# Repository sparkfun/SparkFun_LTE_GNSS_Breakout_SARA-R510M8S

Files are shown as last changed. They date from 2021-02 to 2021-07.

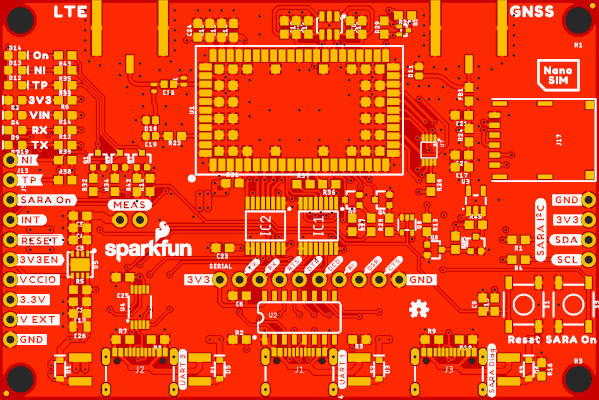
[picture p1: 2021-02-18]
img/Top.png

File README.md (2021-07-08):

# SparkFun LTE GNSS Breakout - SARA-R510M8S

LTE GNSS Breakout - SARA-R5 (GPS-18031 (https://www.sparkfun.com/products/18031)

The u-blox SARA-R510M8S module is a secure cloud LTE Cat M1, LTE Cat NB2 solution based on u-blox's UBX-R5 cellular chipset.
The SARA-R510M8S has an integrated u-blox M8 GNSS receiver chip and a separate GNSS antenna interface.

The SARA-R5's UART interface can be configured into one of five variants, providing connectivity over one or two UARTs. A separate USB port
provides access to the SARA's trace log for diagnostic purposes. This breakout provides access to all three interfaces (UART1, UART2 and SARA Diag)
via three separate USB-C connections. All eight 3.3V serial signals are available on a 0.1"-pitch breakout header.

## Repository Contents

- **/Documentation** - Datasheets etc.
- **/Hardware** - Eagle PCB, SCH and LBR design files. Full schematic in PDF format.
- **[LICENSE.md](./LICENSE.md)** - License details

## Documentation

- **[SparkFun u-blox SARA-R5 Arduino Library](https://github.com/sparkfun/SparkFun_u-blox_SARA-R5_Arduino_Library)** - Arduino library for the SARA-R5 module.
- **[Hookup Guide](https://learn.sparkfun.com/tutorials/lte-gnss-breakout---sara-r5-hookup-guide)** - Hookup Guide for the LTE GNSS Breakout - SARA-R5.

## UART 1 & 2

The board comes pre-configured to support interface variants 0 and 1 (single UART, 8-wire connectivity). If you want to use variants 2-4 (dual UART),
you will need to:
- Open the split pads adjacent to the **DTR**, **DCD**, **RI** and **DSR** breakout pins
- Close the solder split pads labelled **TXD2**, **RXD2**, **RTS2** and **CTS2**
- Open the **OUT** split pad labelled **DSR O RTS2 I** and close the adjacent **IN** solder split pad

The serial signals on the breakout pins are all 3.3V. Level-shifting circuits connect them to the SARA's 1.8V UART pins.

## Power Options

The board can draw 5V power from any or all of the USB-C connectors. Optionally, you can provide power via the **V EXT** breakout pin: 3.7V Min; 6.0V Max.

If you want to use **V EXT** as an output, you can bypass the DVEXT protection diode by closing the **V EXT Diode** solder split pad.

The board's 3.3V current draw can be monitored via the **MEAS** header pins. Open the split pad linking these pins if required.

## Additional Breakout Pins

- **NI** - Network Indicator will be _low_ when the SARA is on and the network is available.
- **TP** - GNSS Timing Pulse (PPS) pin will pulse low/high when configured by the **+UTIME=1,1** command. Please see the [AT Commands Manual](./Documents/SARA-R5_ATCommands_(UBX-19047455).pdf) for more details.
- **SARA On** - pull low for 5 seconds then release to turn the SARA off. Pull low briefly again to turn the SARA back on. You can tell if the SARA is powered by monitoring the **VCCIO** 1.8V pin.
- **INT** - by default this pin is connected to the SARA's bi-directional **EXT INT** pin. It can optionally be connected to **GPIO3** by reconfiguring the **SARA INT** split pad.
- **~RESET** - pull low and release to reset the SARA.
- **SARA I<sup>2</sup>C** - provides access to the SARA's I<sup>2</sup>C SDA and SCL pins.
- **3V3EN** - pull this pin low to disable the 3.3V supply completely. _Note: you may want to turn the SARA off using the **SARA On** pin first, so it disconnects from the network correctly._

**NI**, **TP**, **SARA On**, **INT**, **~RESET**, **SDA** and **SCL** are all 3.3V. Level-shifting circuits connect them to the SARA's 1.8V I/O pins.

_**Important Note**: **VCCIO** is 1.8V. You may need to connect it to an analog input to sense the voltage correctly._

_**Important Note**: **3V3EN** is pulled-up to VIN (5V) via a 100K resistor. We recommend using a switch or open-collector / open-drain output to pull **3V3EN** low._

## Switches

- **Reset** - pressing this switch will reset the SARA.
- **SARA On** - pressing and holding this switch for five seconds will turn the SARA off. Press briefly to turn the SARA back on again.

## GNSS Antenna Power

The board provides 3.3V power for an active GNSS antenna. By default the antenna power is enabled whenever the SARA is on. You can reconfigure the **ANT GNSS PWR**
split pad to optionally control the antenna power via the SARA's GPIO2 pin.

The GPIO2 pin can be controlled using the **+UGPIOC=23,0,1** command.
Please see the [AT Commands Manual](./Documents/SARA-R5_ATCommands_(UBX-19047455).pdf) for more details.

## Product Versions

- [GPS-18031](https://www.sparkfun.com/products/18031) - Initial Release

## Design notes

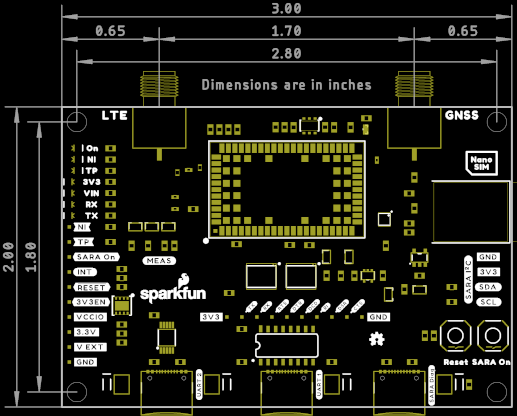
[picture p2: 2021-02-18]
img/Dimensions.png

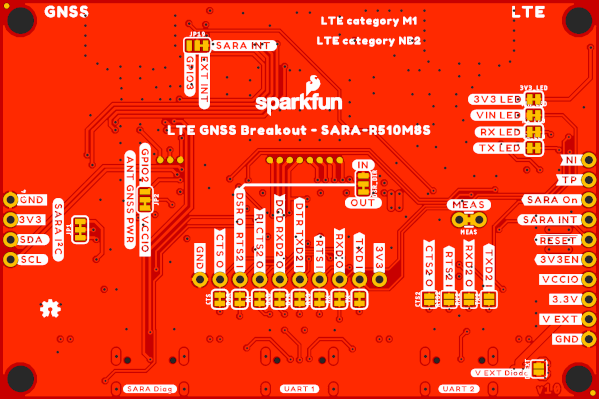
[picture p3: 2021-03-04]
img/Bottom.png

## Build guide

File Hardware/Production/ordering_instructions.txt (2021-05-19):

panel size, 167x126mm
PCB thickness, 1.6mm
number of layers, 4
soldermask color, Red
silkscreen color, White
oz copper, 1oz
finish, HASL lead free
stencils, top
pcs per panel, 4
min trace width, 0.2032mm / 0.0080in
min drill size, 0.2840mm / 0.0112in
filename to layer stackup 1/2/3/4: GTL, GL2, GL3, GBL

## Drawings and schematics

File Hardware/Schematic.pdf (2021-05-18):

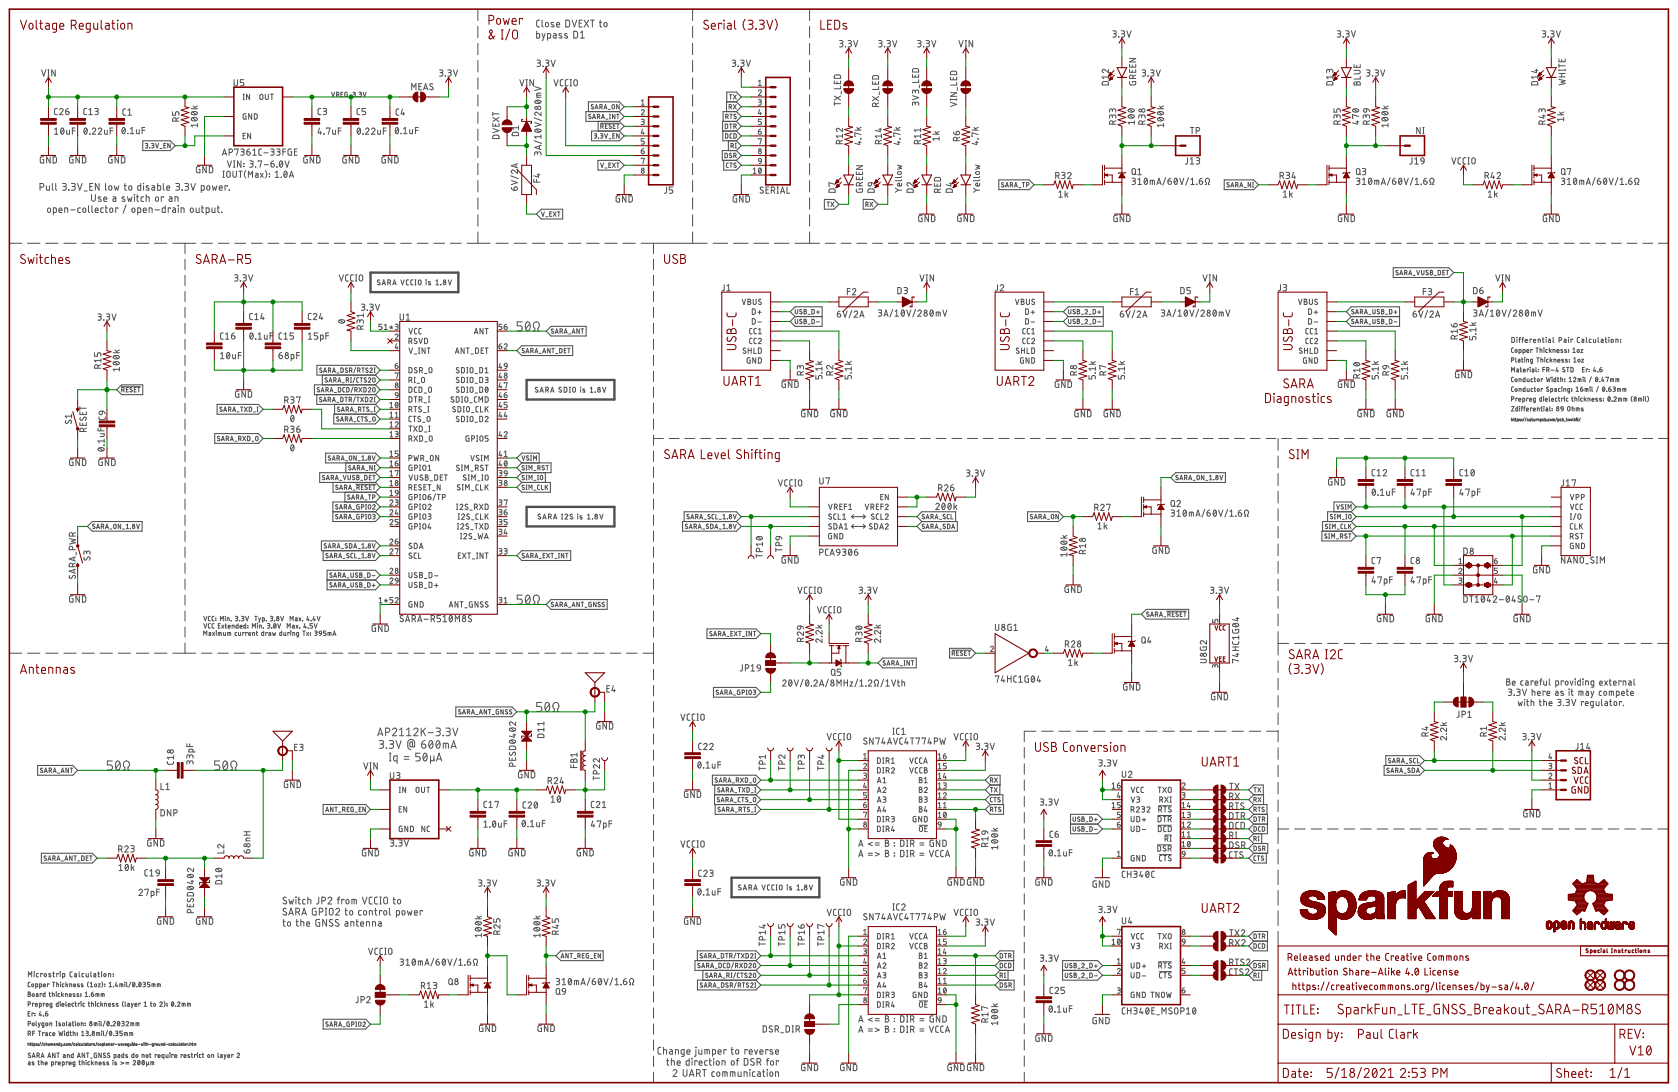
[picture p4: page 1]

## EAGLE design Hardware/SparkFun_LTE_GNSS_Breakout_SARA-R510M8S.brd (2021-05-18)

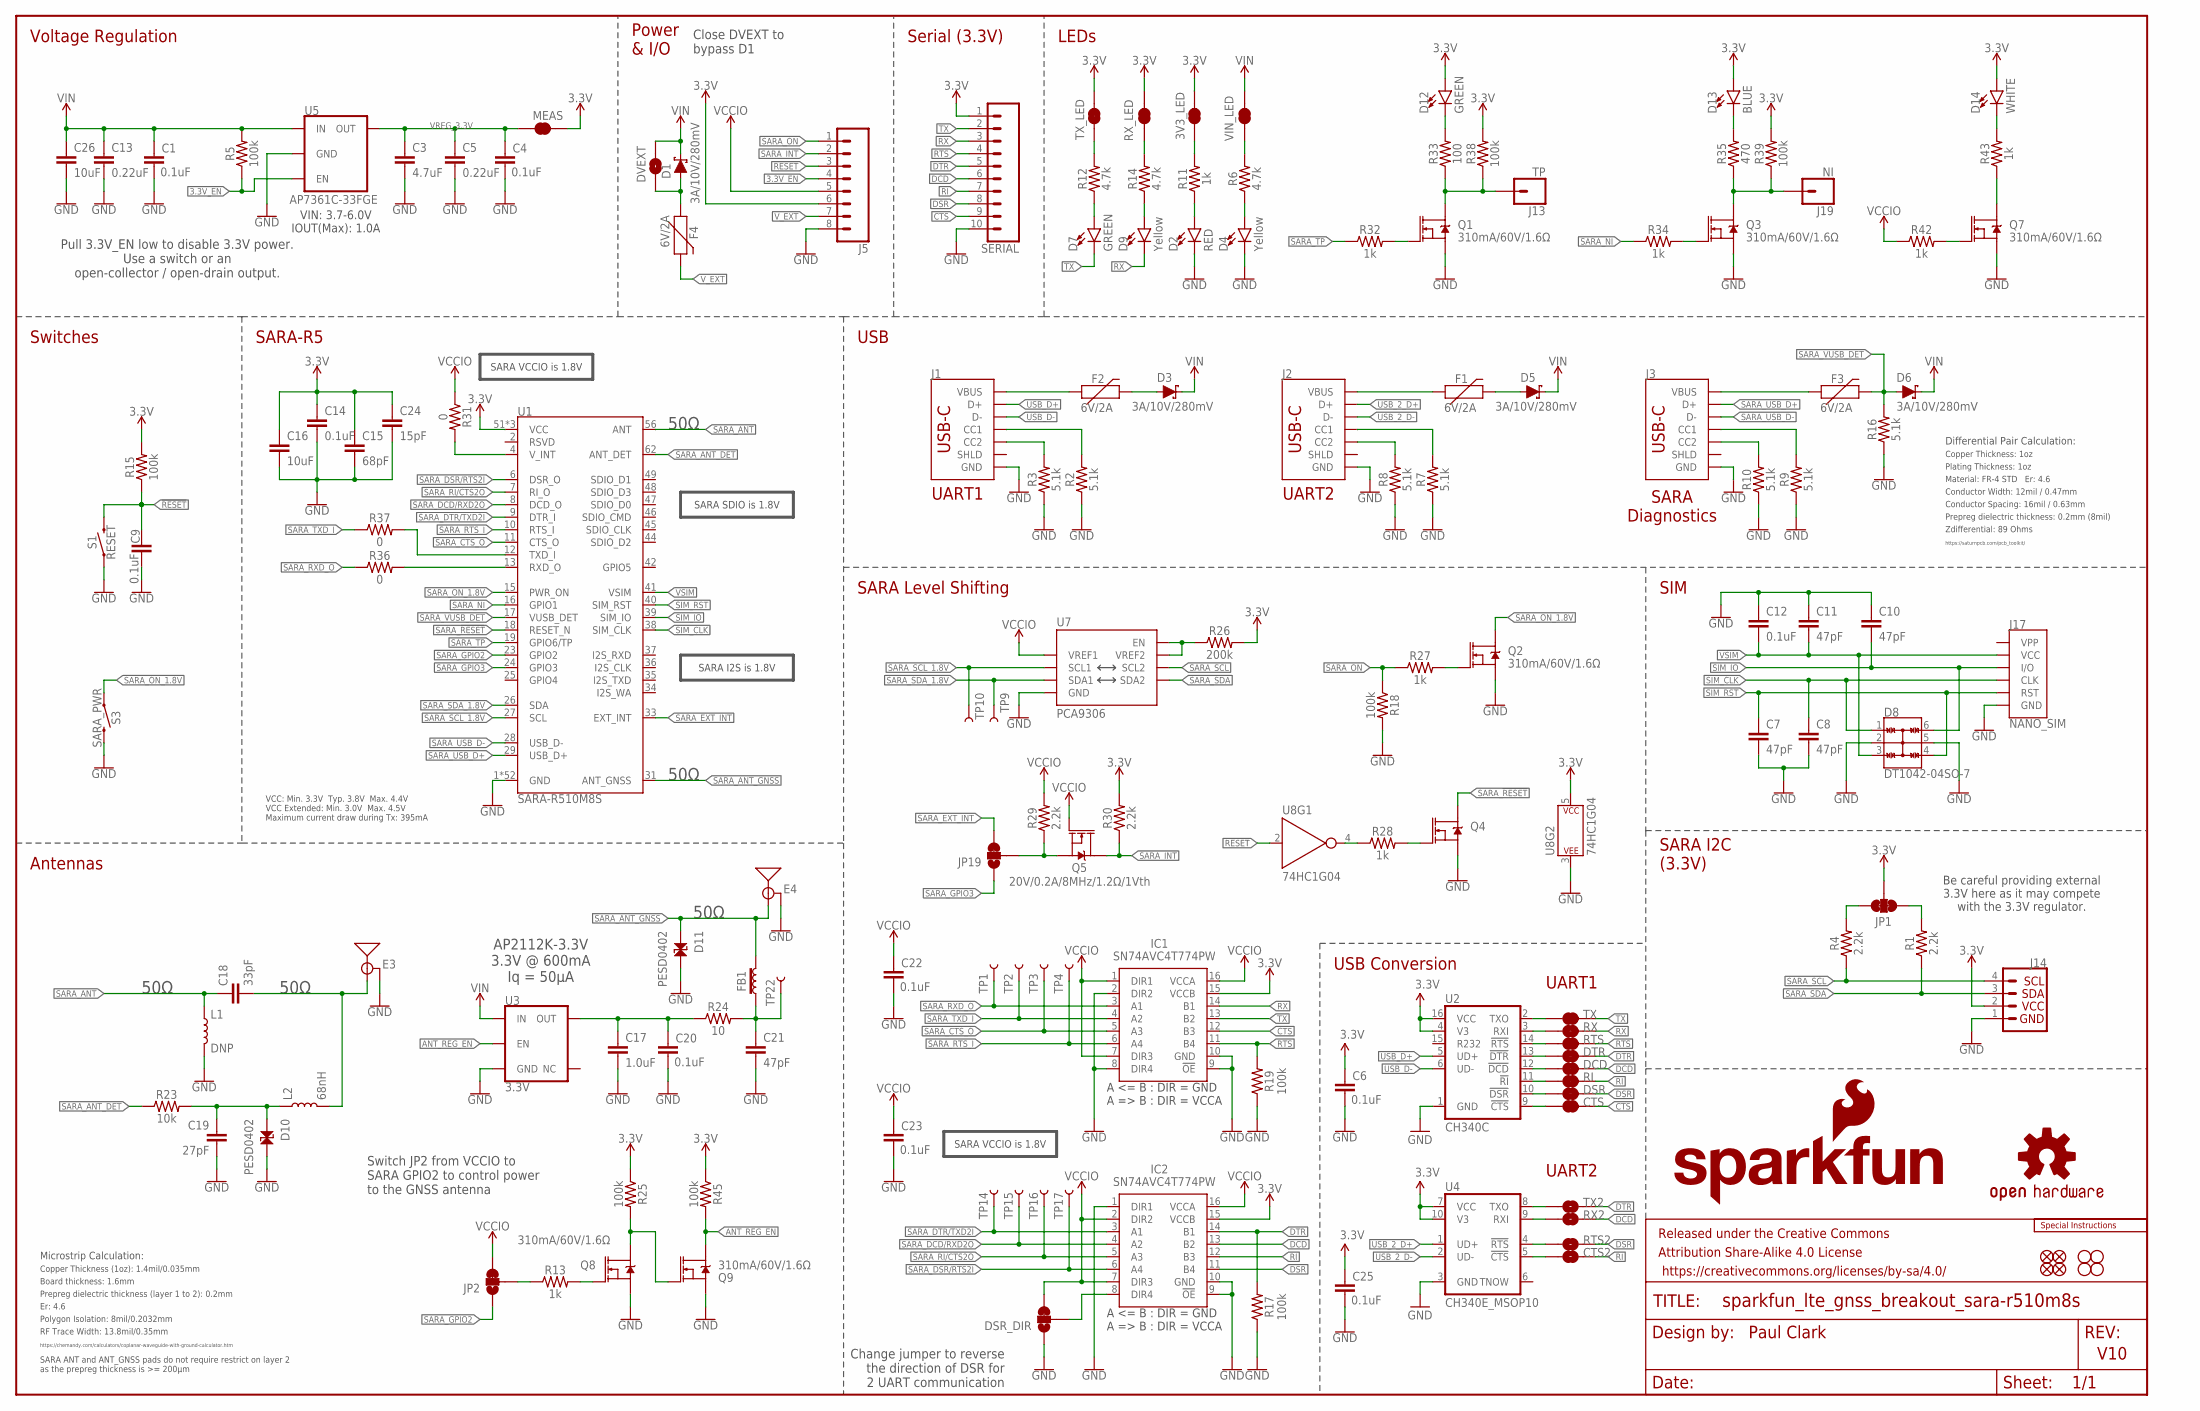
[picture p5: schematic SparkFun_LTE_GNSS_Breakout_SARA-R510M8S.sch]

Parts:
3V3_LED: JUMPER-SMT_2_NC_TRACE_SILK; SMT-JUMPER_2_NC_TRACE_SILK
C1, C4, C6, C9, C12, C14, C20, C22, C23, C25: 0.1uF; 0603
C3: 4.7uF; 0603
C5, C13: 0.22uF; 0603
C7, C8, C10, C11, C21: 47pF; 0603
C15: 68pF; 0603
C16: 10uF; 0603
C17: 1.0uF; 0603
C18: 33pF; 0402-TIGHT
C19: 27pF; 0402
C24: 15pF; 0603
C26: 10uF; 0805
CTS: JUMPER-SMT_2_NC_TRACE_SILK; SMT-JUMPER_2_NC_TRACE_SILK
CTS2: JUMPER-SMT_2_NO_SILK; SMT-JUMPER_2_NO_SILK
D1, D3, D5, D6: 3A/10V/280mV; SOD-323
D2: RED; LED-0603
D4, D9: Yellow; LED-0603
D7, D12: GREEN; LED-0603
D8: DT1042-04SO-7; SOT23-6L
D10, D11: PESD0402; 0402
D13: BLUE; LED-0603
D14: WHITE; LED-0603
DCD: JUMPER-SMT_2_NC_TRACE_SILK; SMT-JUMPER_2_NC_TRACE_SILK
DSR: JUMPER-SMT_2_NC_TRACE_SILK; SMT-JUMPER_2_NC_TRACE_SILK
DSR_DIR: JUMPER-SMT_3_1-NC_TRACE_SILK; SMT-JUMPER_3_1-NC_TRACE_SILK
DTR: JUMPER-SMT_2_NC_TRACE_SILK; SMT-JUMPER_2_NC_TRACE_SILK
DVEXT: JUMPER-SMT_2_NO_SILK; SMT-JUMPER_2_NO_SILK
E3, E4: ANTENNA-SMA-GROUNDEDEDGE_SMA_SMD; SMA-EDGE-SMD
F1, F2, F3, F4: 6V/2A; 1210
FB1: 30Ω/1.8A; 0603
FD1, FD2, FD3, FD4: FIDUCIALUFIDUCIAL; FIDUCIAL-MICRO
FRAME1: FRAME-LEDGER; CREATIVE_COMMONS
H1, H2, H3, H4: STAND-OFF
IC1, IC2: SN74AVC4T774PW; SOP65P640X120-16N
J1, J2, J3: USB_C_4-LAYER_PADS; USB-C-16P_4LAYER-PADS
J5: CONN_08NO_SILK_DNP; 1X08_NO_SILK
J13: TP; 1X01_NO_SILK
J14: I2C_STANDARD_NO_SILK; 1X04_NO_SILK
J17: NANO_SIM; NANO_SIM_WURTH_693043020611
J19: NI; 1X01_NO_SILK
JP1: JUMPER-SMT_3_2-NC_TRACE_SILK; SMT-JUMPER_3_2-NC_TRACE_SILK
JP2, JP19: JUMPER-SMT_3_1-NC_TRACE_SILK; SMT-JUMPER_3_1-NC_TRACE_SILK
L1: DNP; 0402_COILCRAFT
L2: 68nH; 0402_COILCRAFT
LOGO1: SFE_LOGO_NAME_FLAME.1_INCH; SFE_LOGO_NAME_FLAME_.1
LOGO3: OSHW-LOGOMINI; OSHW-LOGO-MINI
LOGO5: SPECIAL_INSTRUCTIONS-ORDERING; ORDERING_INSTRUCTIONS
MEAS: JUMPER-COMBO_2_NC_TRACE; COMBO-JUMPER_2_NC_TRACE
Q1, Q2, Q3, Q4, Q7, Q8, Q9: 310mA/60V/1.6Ω; SOT323
Q5: 20V/0.2A/8MHz/1.2Ω/1Vth; SOT-416FL
R1, R4, R29, R30: 2.2k; 0603
R2, R3, R7, R8, R9, R10, R16: 5.1k; 0603
R5, R15, R17, R18, R19, R25, R38, R39, R45: 100k; 0603
R6, R12, R14: 4.7k; 0603
R11, R13, R27, R28, R32, R34, R42, R43: 1k; 0603
R23: 10k; 0603
R24: 10; 0603
R26: 200k; 0603
R31, R36, R37: 0; 0603
R33: 100; 0603
R35: 470; 0603
RI: JUMPER-SMT_2_NC_TRACE_SILK; SMT-JUMPER_2_NC_TRACE_SILK
RTS: JUMPER-SMT_2_NC_TRACE_SILK; SMT-JUMPER_2_NC_TRACE_SILK
RTS2: JUMPER-SMT_2_NO_SILK; SMT-JUMPER_2_NO_SILK
RX: JUMPER-SMT_2_NC_TRACE_SILK; SMT-JUMPER_2_NC_TRACE_SILK
RX2: JUMPER-SMT_2_NO_SILK; SMT-JUMPER_2_NO_SILK
RX_LED: JUMPER-SMT_2_NC_TRACE_SILK; SMT-JUMPER_2_NC_TRACE_SILK
S1: RESET; TACTILE_SWITCH_SMD_5.2MM
S3: SARA_PWR; TACTILE_SWITCH_SMD_5.2MM
SERIAL: CONN_10NO_SILK_PTH_FEMALE; 1X10_NO_SILK
TP1, TP2, TP3, TP4, TP9, TP10, TP14, TP15, TP16, TP17, TP22: TEST-POINT3; PAD.03X.03
TX: JUMPER-SMT_2_NC_TRACE_SILK; SMT-JUMPER_2_NC_TRACE_SILK
TX2: JUMPER-SMT_2_NO_SILK; SMT-JUMPER_2_NO_SILK
TX_LED: JUMPER-SMT_2_NC_TRACE_SILK; SMT-JUMPER_2_NC_TRACE_SILK
U1: SARA-R510M8S; SARA-LGA
U2: CH340C; SO016
U3: 3.3V; SOT23-5
U4: CH340E_MSOP10; MSOP10
U5: AP7361C-33FGE; UDFN-8
U7: PCA9306; VSSOP_8PIN
U8: 74HC1G04; SOT353
VIN_LED: JUMPER-SMT_2_NC_TRACE_SILK; SMT-JUMPER_2_NC_TRACE_SILK

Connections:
3.3V: 3V3_LED.2, C6.1, C14.1, C15.1, C16.1, C24.1, C25.1, D12.A, D13.A, D14.A, IC1.15 (VCCB), IC2.15 (VCCB), J5.6, J14.2, JP1.2, MEAS.2, MEAS.4 (2), R15.2, R25.1, R26.2, R30.2, R38.2, R39.2, R45.1, RX_LED.2, SERIAL.1, TX_LED.2, U1.51 (VCC), U1.52 (VCC), U1.53 (VCC), U2.4 (V3), U2.16 (VCC), U4.7 (VCC), U4.10 (V3), U8.5 (P$V+)
3.3V_EN: J5.4, R5.1, U5.5 (EN)
!RESET!: C9.1, J5.3, R15.1, S1.3 (2), S1.4 (2), U8.2 (A)
ANT_REG_EN: Q9.3 (D), R45.2, U3.3 (EN)
CTS: CTS.2, IC1.12 (B3), SERIAL.9
DCD: DCD.2, IC2.13 (B2), RX2.2, SERIAL.6
DSR: DSR.2, IC2.11 (B4), RTS2.2, SERIAL.8
DTR: DTR.2, IC2.14 (B1), R17.2, SERIAL.5, TX2.2
GND: C1.2, C3.2, C4.2, C5.2, C6.2, C7.2, C8.2, C9.2, C10.1, C11.1, C12.1, C13.2, C14.2, C15.2, C16.2, C17.2, C19.2, C20.2, C21.2, C22.2, C23.2, C24.2, C25.2, C26.2, D2.C, D4.C, D8.2, D8.5, D10.2, D11.2, DSR_DIR.1, E3.GND@0 (GND), E3.GND@1 (GND), E4.GND@0 (GND), E4.GND@1 (GND), IC1.2 (DIR2), IC1.8 (DIR4), IC1.9 (!OE), IC1.10 (GND), IC2.1 (DIR1), IC2.9 (!OE), IC2.10 (GND), J1.GND, J1.GND2 (GND), J2.GND, J2.GND2 (GND), J3.GND, J3.GND2 (GND), J5.8, J14.1, J17.C5 (GND), L1.P$2 (2), Q1.2 (S), Q2.2 (S), Q3.2 (S), Q4.2 (S), Q7.2 (S), Q8.2 (S), Q9.2 (S), R2.1, R3.1, R7.1, R8.1, R9.1, R10.1, R16.1, R17.1, R18.2, R19.1, S1.1, S1.2 (1), S3.3 (2), S3.4 (2), SERIAL.10, U1.1 (GND), U1.3 (GND), U1.5 (GND), U1.14 (GND), U1.20 (GND), U1.21 (GND), U1.22 (GND), U1.30 (GND), U1.32 (GND), U1.43 (GND), U1.50 (GND), U1.54 (GND), U1.55 (GND), U1.57 (GND), U1.58 (GND), U1.59 (GND), U1.60 (GND), U1.61 (GND), U1.63 (GND), U1.64 (GND), U1.65 (GND), U1.66 (GND), U1.67 (GND), U1.68 (GND), U1.69 (GND), U1.70 (GND), U1.71 (GND), U1.72 (GND), U1.73 (GND), U1.74 (GND), U1.75 (GND), U1.76 (GND), U1.77 (GND), U1.78 (GND), U1.79 (GND), U1.80 (GND), U1.81 (GND), U1.82 (GND), U1.83 (GND), U1.84 (GND), U1.85 (GND), U1.86 (GND), U1.87 (GND), U1.88 (GND), U1.89 (GND), U1.90 (GND), U1.91 (GND), U1.92 (GND), U1.93 (GND), U1.94 (GND), U1.95 (GND), U1.96 (GND), U2.1 (GND), U3.2 (GND), U4.3 (GND), U5.4 (GND), U5.EP (GND), U7.P1 (GND), U8.3 (P$V-)
unnamed: R6.2, VIN_LED.1
unnamed: JP1.3, R4.2
unnamed: JP1.1, R1.2
unnamed: D3.A, F2.2
unnamed: J2.A5 (CC1), R7.2
unnamed: 3V3_LED.1, R11.2
unnamed: D2.A, R11.1
unnamed: D4.A, R6.1
unnamed: J2.B5 (CC2), R8.2
unnamed: J1.A5 (CC1), R2.2
unnamed: J1.B5 (CC2), R3.2
unnamed: D5.A, F1.2
unnamed: F1.1, J2.VBUS1 (VBUS), J2.VBUS2 (VBUS)
unnamed: J3.A5 (CC1), R9.2
unnamed: C18.2, E3.SIG (SIGNAL), L2.P$2 (2)
unnamed: C19.1, D10.1, L2.P$1 (1), R23.2
unnamed: J3.B5 (CC2), R10.2
unnamed: F3.1, J3.VBUS1 (VBUS), J3.VBUS2 (VBUS)
unnamed: F2.1, J1.VBUS1 (VBUS), J1.VBUS2 (VBUS)
unnamed: TX.1, U2.2 (TXO)
unnamed: RX.1, U2.3 (RXI)
unnamed: R26.1, U7.P7 (VREF2), U7.P8 (EN)
unnamed: DSR_DIR.2, IC2.8 (DIR4)
unnamed: C17.1, C20.1, R24.1, U3.5 (OUT)
unnamed: C21.1, FB1.1, R24.2, TP22.P$1
unnamed: Q2.1 (G), R27.2
unnamed: Q4.1 (G), R28.2
unnamed: R28.1, U8.4 (Y)
unnamed: RTS.1, U2.14 (!RTS)
unnamed: DTR.1, U2.13 (!DTR)
unnamed: R31.2, U1.4 (V_INT)
unnamed: Q1.1 (G), R32.2
unnamed: J13.1, Q1.3 (D), R33.1, R38.1
unnamed: D12.C, R33.2
unnamed: Q3.1 (G), R34.2
unnamed: J19.1, Q3.3 (D), R35.1, R39.1
unnamed: D13.C, R35.2
unnamed: R36.2, U1.13 (RXD_O)
unnamed: R37.2, U1.12 (TXD_I)
unnamed: Q8.1 (G), R13.2
unnamed: DCD.1, U2.12 (!DCD)
unnamed: Q8.3 (D), Q9.1 (G), R25.2
unnamed: JP19.2, Q5.2 (S), R29.1
unnamed: RI.1, U2.11 (!RI)
unnamed: DSR.1, U2.10 (!DSR)
unnamed: CTS.1, U2.9 (!CTS)
unnamed: Q7.1 (G), R42.2
unnamed: TX2.1, U4.8 (TXO)
unnamed: D14.C, R43.2
unnamed: RX2.1, U4.9 (RXI)
unnamed: RTS2.1, U4.4 (!RTS)
unnamed: CTS2.1, U4.5 (!CTS)
unnamed: R12.2, TX_LED.1
unnamed: D7.A, R12.1
unnamed: R14.2, RX_LED.1
unnamed: D9.A, R14.1
unnamed: D1.A, DVEXT.1, F4.1
unnamed: JP2.2, R13.1
RI: CTS2.2, IC2.12 (B3), RI.2, SERIAL.7
RTS: IC1.11 (B4), R19.2, RTS.2, SERIAL.4
RX: D9.C, IC1.14 (B1), RX.2, SERIAL.3
SARA_!ON!: Q7.3 (D), R43.1
SARA_!RESET!: Q4.3 (D), U1.18 (RESET_N)
SARA_ANT: C18.1, L1.P$1 (1), U1.56 (ANT)
SARA_ANT_DET: R23.1, U1.62 (ANT_DET)
SARA_ANT_GNSS: D11.1, E4.SIG (SIGNAL), FB1.2, U1.31 (ANT_GNSS)
SARA_CTS_O: IC1.5 (A3), TP3.P$1, U1.11 (CTS_O)
SARA_DCD/RXD2O: IC2.4 (A2), TP15.P$1, U1.8 (DCD_O)
SARA_DSR/RTS2I: IC2.6 (A4), TP17.P$1, U1.6 (DSR_O)
SARA_DTR/TXD2I: IC2.3 (A1), TP14.P$1, U1.9 (DTR_I)
SARA_EXT_INT: JP19.3, U1.33 (EXT_INT)
SARA_GPIO2: JP2.1, U1.23 (GPIO2)
SARA_GPIO3: JP19.1, U1.24 (GPIO3)
SARA_INT: J5.2, Q5.3 (D), R30.1
SARA_NI: R34.1, U1.16 (GPIO1)
SARA_ON: J5.1, R18.1, R27.1
SARA_ON_1.8V: Q2.3 (D), S3.1, S3.2 (1), U1.15 (PWR_ON)
SARA_RI/CTS2O: IC2.5 (A3), TP16.P$1, U1.7 (RI_O)
SARA_RTS_I: IC1.6 (A4), TP4.P$1, U1.10 (RTS_I)
SARA_RXD_O: IC1.3 (A1), R36.1, TP1.P$1
SARA_SCL: J14.4, R4.1, U7.P6 (SCL2)
SARA_SCL_1.8V: TP10.P$1, U1.27 (SCL), U7.P3 (SCL1)
SARA_SDA: J14.3, R1.1, U7.P5 (SDA2)
SARA_SDA_1.8V: TP9.P$1, U1.26 (SDA), U7.P4 (SDA1)
SARA_TP: R32.1, U1.19 (GPIO6/TP)
SARA_TXD_I: IC1.4 (A2), R37.1, TP2.P$1
SARA_USB_D+: J3.A6 (D+), J3.B6 (D+), U1.29 (USB_D+)
SARA_USB_D-: J3.A7 (D-), J3.B7 (D-), U1.28 (USB_D-)
SARA_VUSB_DET: D6.A, F3.2, R16.2, U1.17 (VUSB_DET)
SIM_CLK: C8.1, D8.1, J17.C3 (CLK), U1.38 (SIM_CLK)
SIM_IO: C10.2, D8.6, J17.C7 (I/O), U1.39 (SIM_IO)
SIM_RST: C7.1, D8.4, J17.C2 (RST), U1.40 (SIM_RST)
TX: D7.C, IC1.13 (B2), SERIAL.2, TX.2
USB_2_D+: J2.A6 (D+), J2.B6 (D+), U4.1 (UD+)
USB_2_D-: J2.A7 (D-), J2.B7 (D-), U4.2 (UD-)
USB_D+: J1.A6 (D+), J1.B6 (D+), U2.5 (UD+)
USB_D-: J1.A7 (D-), J1.B7 (D-), U2.6 (UD-)
VCCIO: C22.1, C23.1, DSR_DIR.3, IC1.1 (DIR1), IC1.7 (DIR3), IC1.16 (VCCA), IC2.2 (DIR2), IC2.7 (DIR3), IC2.16 (VCCA), J5.5, JP2.3, Q5.1 (G), R29.2, R31.1, R42.1, U7.P2 (VREF1)
VIN: C1.1, C13.1, C26.1, D1.C, D3.C, D5.C, D6.C, DVEXT.2, R5.2, U3.1 (IN), U5.8 (IN), VIN_LED.2
VREG_3.3V: C3.1, C4.1, C5.1, MEAS.1, MEAS.3 (1), U5.1 (OUT)
VSIM: C11.2, C12.2, D8.3, J17.C1 (VCC), U1.41 (VSIM)
V_EXT: F4.2, J5.7

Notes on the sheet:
USB
Voltage Regulation
Paul Clark
V10
VIN: 3.7-6.0V IOUT(Max): 1.0A
LEDs
Switches
SARA-R5
SIM
SARA SDIO is 1.8V
50Ω
SARA I2S is 1.8V
Power & I/O
SARA I2C (3.3V)
Be careful providing external 3.3V here as it may compete with the 3.3V regulator.
SARA VCCIO is 1.8V
Plating Thickness: 1oz
Material: FR-4 STD Er: 4.6
Copper Thickness: 1oz
Conductor Spacing: 16mil / 0.63mm
Conductor Width: 12mil / 0.47mm
Prepreg dielectric thickness: 0.2mm (8mil)
https://saturnpcb.com/pcb_toolkit/
Differential Pair Calculation:
Zdifferential: 89 Ohms
Antennas
VCC: Min. 3.3V Typ. 3.8V Max. 4.4V VCC Extended: Min. 3.0V Max. 4.5V Maximum current draw during Tx: 395mA
Board thickness: 1.6mm
Er: 4.6
Copper Thickness (1oz): 1.4mil/0.035mm
RF Trace Width: 13.8mil/0.35mm
Polygon Isolation: 8mil/0.2032mm
Prepreg dielectric thickness (layer 1 to 2): 0.2mm
https://chemandy.com/calculators/coplanar-waveguide-with-ground-calculator.htm
Microstrip Calculation:
SARA ANT and ANT_GNSS pads do not require restrict on layer 2 as the prepreg thickness is >= 200µm
AP2112K-3.3V 3.3V @ 600mA Iq = 50µA
SARA Level Shifting
Change jumper to reverse the direction of DSR for 2 UART communication
USB Conversion

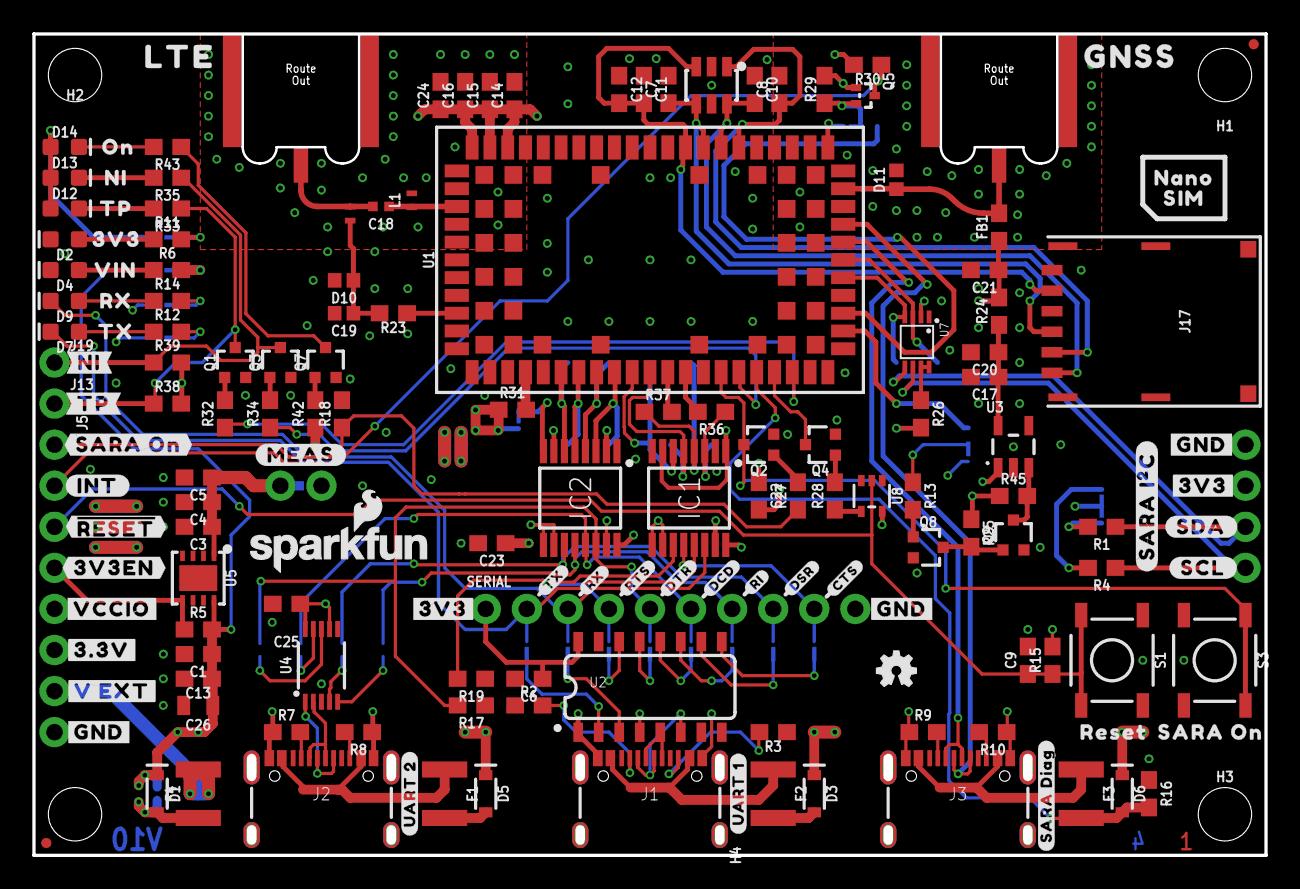
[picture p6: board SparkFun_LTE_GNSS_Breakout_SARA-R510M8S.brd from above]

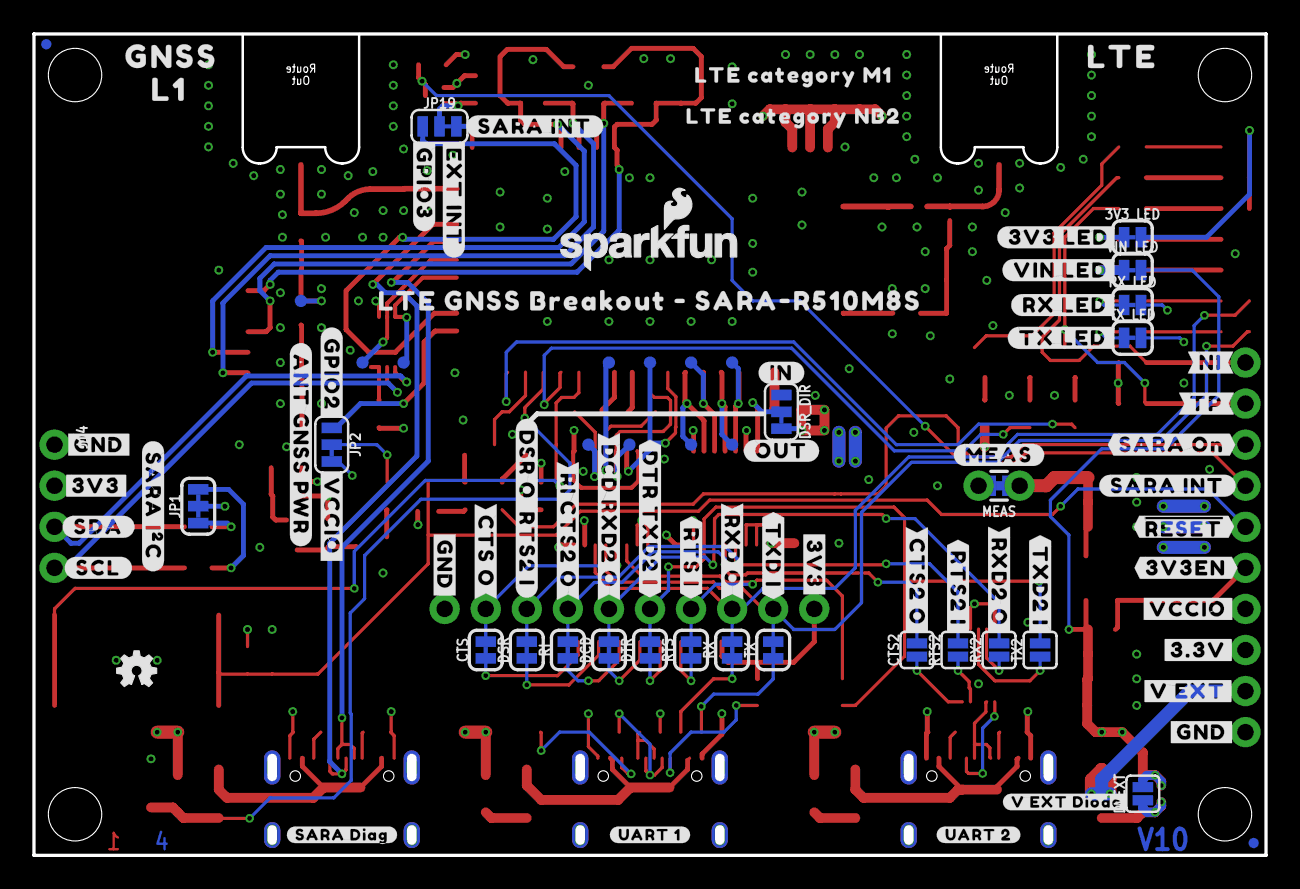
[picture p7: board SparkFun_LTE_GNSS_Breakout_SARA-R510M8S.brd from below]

Board: 4 copper layers, 76.2 x 50.8 mm, 256 parts (90 on the bottom side), 111 nets.

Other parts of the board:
LOGO2: OSHW-LOGOMINI; OSHW-LOGO-MINI
LOGO4: SFE_LOGO_NAME_FLAME.1_INCH; SFE_LOGO_NAME_FLAME_.1
U$1, U$2, U$3, U$11: #3V3#1
U$4: #TX_LED#0
U$5, U$23: #SARA_I�C#0
U$6, U$7: #V_EXT#0
U$8, U$9: #3V3EN#0
U$10, U$13: ##RESET##0
U$12, U$22: #GND#0
U$14: #INT#0
U$15, U$71: #SARA_INT#0
U$16, U$17: #SARA_ON#0
U$18: RX0
U$19, U$87: #MEAS#2
U$20: #RX_LED#0
U$21: TX0
U$24: #TX#0
U$25: #RX#0
U$26, U$27: #SCL#3
U$28: #RTS#0
U$29: #DTR#0
U$30, U$37: #SDA#2
U$31: #DCD#0
U$32: #RI#0
U$33: #DSR#0
U$34: #CTS#0
U$35: #RXD_O#0
U$36: 3V37
U$38: #TXD_I#0
U$39: #CTS_O#0
U$40: #RTS_I#0
U$41: #DTR_TXD2_I#0
U$42: L10
U$43: #DCD_RXD2_O#0
U$44: #RXD2_O#0
U$45: RESET6
U$46: VIN8
U$47: #RI_CTS2_O#0
U$48: #CTS2_O#0
U$49: #DSR_O__RTS2_I#0
U$50: #RTS2_I#0
U$51: #V_EXT_DIODE#0
U$52: #OUT#0
U$53: #IN#0
U$54: #VIN_LED#0
U$55, U$56, U$81, U$82: #GND#4
U$57, U$58: #TP#0
U$59, U$60: #NI#0
U$61: #3V3_LED#0
U$62, U$63: #UART_2#0
U$64, U$65: #UART_1#0
U$66, U$67: #SARA_DIAG#0
U$68, U$80, U$83: #VCCIO#0
U$69: #GPIO2#0
U$70: #ANT_GNSS_PWR#0
U$72: #TXD2_I#0
U$73: LTE_CATEGORY_M10
U$74: LTE_CATEGORY_NB20
U$75: LTE_GNSS_BREAKOUT_#_SARA#R510M8S0
U$76, U$79: #3#3V#0
U$88, U$89: LTE0
U$90: NI0
U$91: TP0
U$99, U$100: GNSS0
U$101: ON0
U$113: SARA_ON0
U$118: #EXT_INT#0
U$119: #GPIO3#0
U$130: NANO0
U$131: SIM0

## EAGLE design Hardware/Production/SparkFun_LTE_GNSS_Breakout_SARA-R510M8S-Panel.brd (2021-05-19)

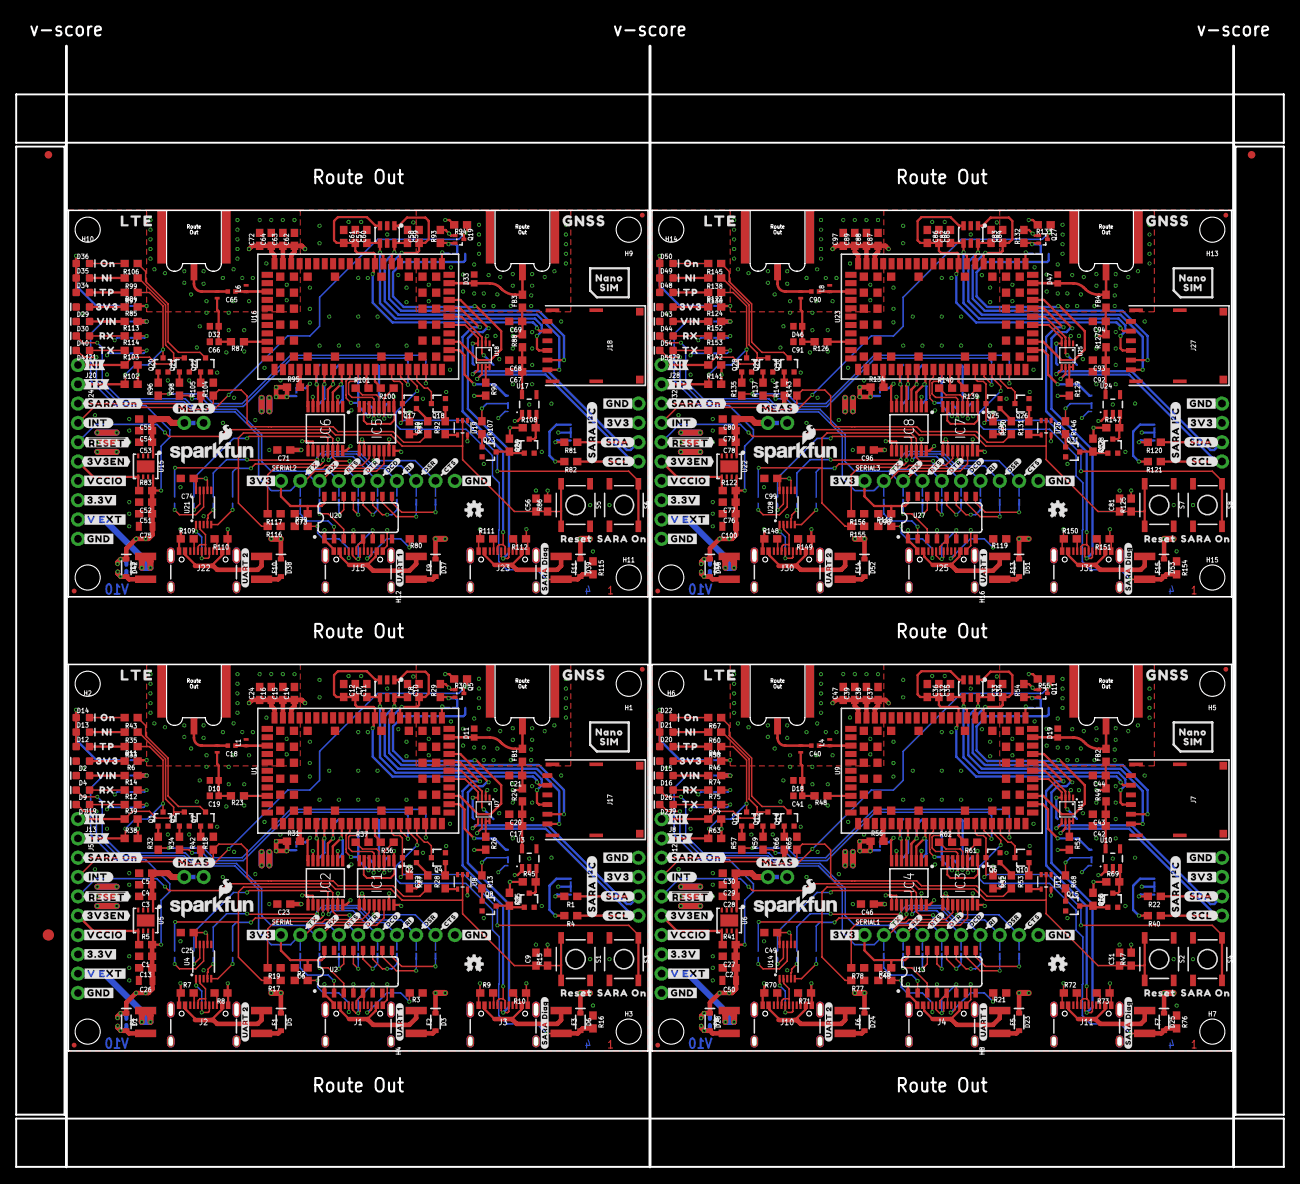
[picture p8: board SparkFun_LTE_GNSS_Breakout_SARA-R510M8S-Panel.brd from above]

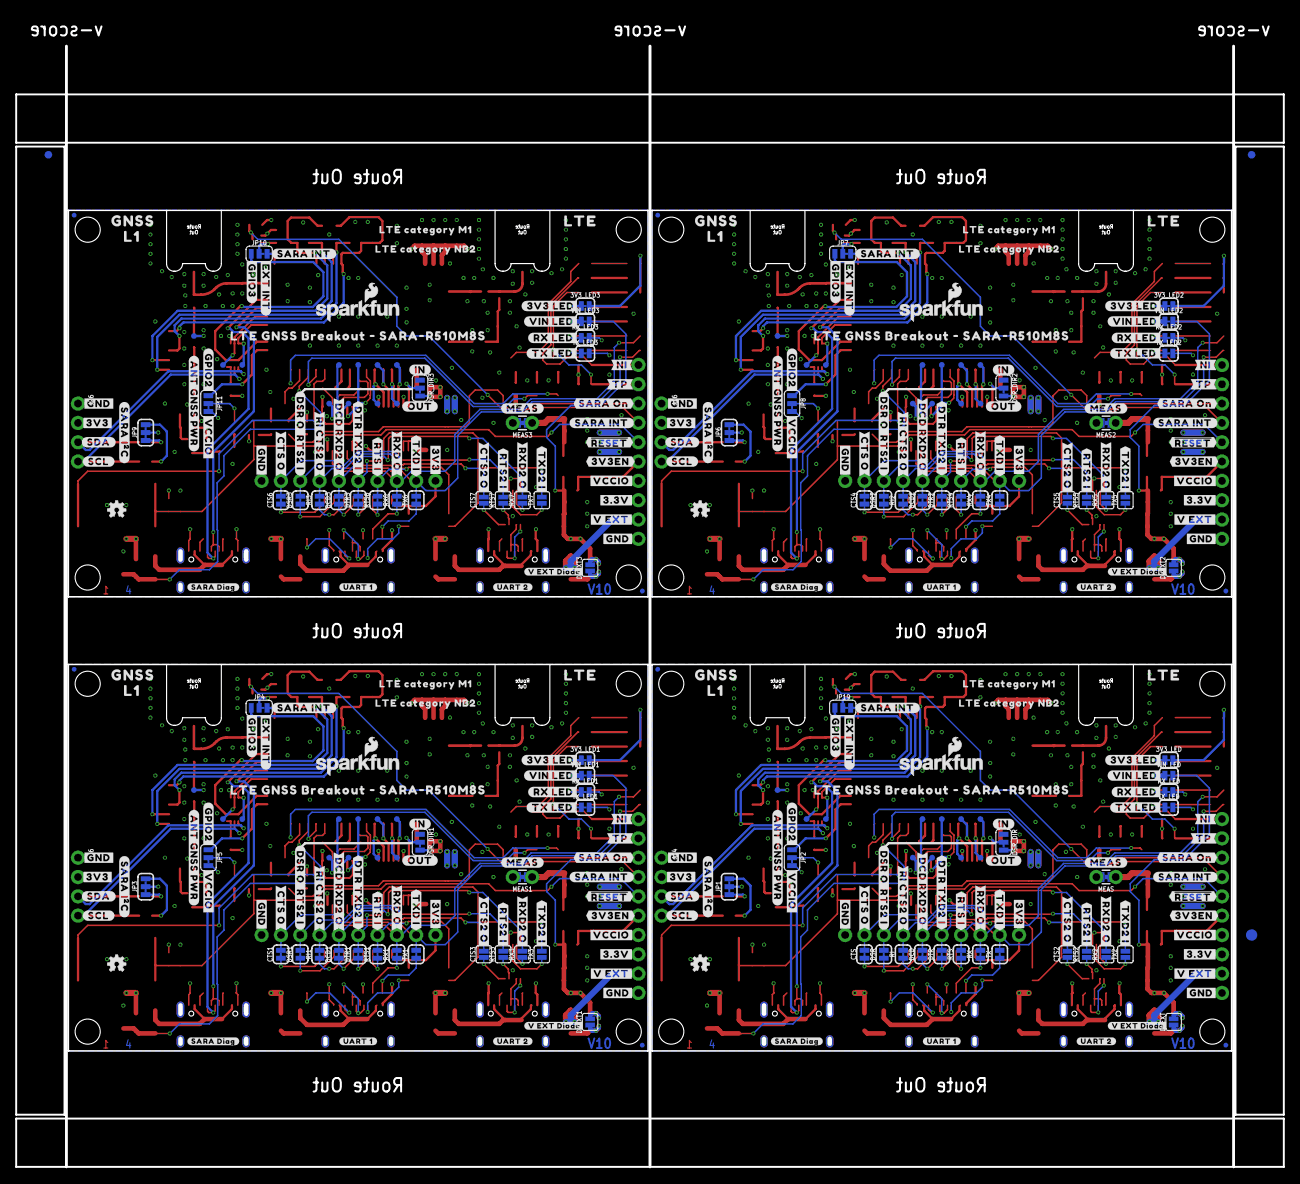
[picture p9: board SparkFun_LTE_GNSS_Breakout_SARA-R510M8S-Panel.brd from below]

Board: 4 copper layers, 166.6 x 147.3 mm, 1022 parts (363 on the bottom side), 444 nets.

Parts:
3V3_LED, 3V3_LED1, 3V3_LED2, 3V3_LED3: SMT-JUMPER_2_NC_TRACE_SILK
C1, C4, C6, C9, C12, C14, C20, C22, C23, C25, C27, C29, C31, C36, C37, C43, C45, C46, C48, C49, C52, C54, C56, C61, C62, C68, C70, C71, C73, C74, C77, C79, C81, C86, C87, C93, C95, C96, C98, C99: 0.1uF; 0603
C2, C5, C13, C30, C51, C55, C76, C80: 0.22uF; 0603
C3, C28, C53, C78: 4.7uF; 0603
C7, C8, C10, C11, C21, C32, C33, C34, C35, C44, C57, C58, C59, C60, C69, C82, C83, C84, C85, C94: 47pF; 0603
C15, C38, C63, C88: 68pF; 0603
C16, C39, C64, C89: 10uF; 0603
C17, C42, C67, C92: 1.0uF; 0603
C18, C40, C65, C90: 33pF; 0402-TIGHT
C19, C41, C66, C91: 27pF; 0402
C24, C47, C72, C97: 15pF; 0603
C26, C50, C75, C100: 10uF; 0805
CTS, CTS1, CTS4, CTS6: JUMPER-SMT_2_NC_TRACE_SILK; SMT-JUMPER_2_NC_TRACE_SILK
CTS2, CTS3, CTS5, CTS7: JUMPER-SMT_2_NO_SILK; SMT-JUMPER_2_NO_SILK
D1, D3, D5, D6, D23, D24, D25, D28, D37, D38, D39, D42, D51, D52, D53, D56: 3A/10V/280mV; SOD-323
D2, D15, D29, D43: RED; LED-0603
D4, D9, D16, D26, D30, D40, D44, D54: Yellow; LED-0603
D7, D12, D20, D27, D34, D41, D48, D55: GREEN; LED-0603
D8, D17, D31, D45: DT1042-04SO-7; SOT23-6L
D10, D11, D18, D19, D32, D33, D46, D47: PESD0402; 0402
D13, D21, D35, D49: BLUE; LED-0603
D14, D22, D36, D50: WHITE; LED-0603
DCD, DCD1, DCD2, DCD3: JUMPER-SMT_2_NC_TRACE_SILK; SMT-JUMPER_2_NC_TRACE_SILK
DSR, DSR1, DSR2, DSR3: JUMPER-SMT_2_NC_TRACE_SILK; SMT-JUMPER_2_NC_TRACE_SILK
DSR_DIR, DSR_DIR1, DSR_DIR2, DSR_DIR3: JUMPER-SMT_3_1-NC_TRACE_SILK; SMT-JUMPER_3_1-NC_TRACE_SILK
DTR, DTR1, DTR2, DTR3: JUMPER-SMT_2_NC_TRACE_SILK; SMT-JUMPER_2_NC_TRACE_SILK
DVEXT, DVEXT1, DVEXT2, DVEXT3: JUMPER-SMT_2_NO_SILK; SMT-JUMPER_2_NO_SILK
E1, E2, E3, E4, E5, E6, E7, E8: ANTENNA-SMA-GROUNDEDEDGE_SMA_SMD; SMA-EDGE-SMD
E$1, E$2, E$3, E$4: FIDUCIAL-1X2
E$5, E$6: FIDUCIAL-1.5X3
F1, F2, F3, F4, F5, F6, F7, F8, F9, F10, F11, F12, F13, F14, F15, F16: 6V/2A; 1210
FB1, FB2, FB3, FB4: 30Ω/1.8A; 0603
FD1, FD2, FD3, FD4, FD5, FD6, FD7, FD8, FD9, FD10, FD11, FD12, FD13, FD14, FD15, FD16: FIDUCIALUFIDUCIAL; FIDUCIAL-MICRO
H1, H2, H3, H4, H5, H6, H7, H8, H9, H10, H11, H12, H13, H14, H15, H16: STAND-OFF
IC1, IC2, IC3, IC4, IC5, IC6, IC7, IC8: SN74AVC4T774PW; SOP65P640X120-16N
J1, J2, J3, J4, J10, J11, J15, J22, J23, J25, J30, J31: USB-C-16P_4LAYER-PADS
J5, J12, J24, J32: 1X08_NO_SILK
J6, J14, J16, J26: 1X04_NO_SILK
J7, J17, J18, J27: NANO_SIM; NANO_SIM_WURTH_693043020611
J8, J13, J20, J28: TP; 1X01_NO_SILK
J9, J19, J21, J29: NI; 1X01_NO_SILK
JP1, JP3, JP6, JP9: SMT-JUMPER_3_2-NC_TRACE_SILK
JP2, JP4, JP5, JP7, JP8, JP10, JP11, JP19: JUMPER-SMT_3_1-NC_TRACE_SILK; SMT-JUMPER_3_1-NC_TRACE_SILK
L1, L4, L6, L8: DNP; 0402_COILCRAFT
L2, L3, L5, L7: 68nH; 0402_COILCRAFT
LOGO1, LOGO4, LOGO5, LOGO7, LOGO9, LOGO11, LOGO13, LOGO15: SFE_LOGO_NAME_FLAME.1_INCH; SFE_LOGO_NAME_FLAME_.1
LOGO2, LOGO3, LOGO6, LOGO8, LOGO10, LOGO12, LOGO14, LOGO16: OSHW-LOGOMINI; OSHW-LOGO-MINI
MEAS, MEAS1, MEAS2, MEAS3: COMBO-JUMPER_2_NC_TRACE
Q1, Q2, Q3, Q4, Q6, Q7, Q8, Q9, Q10, Q12, Q13, Q14, Q15, Q16, Q17, Q18, Q20, Q21, Q22, Q23, Q24, Q25, Q26, Q28, Q29, Q30, Q31, Q32: 310mA/60V/1.6Ω; SOT323
Q5, Q11, Q19, Q27: 20V/0.2A/8MHz/1.2Ω/1Vth; SOT-416FL
R1, R4, R22, R29, R30, R40, R54, R55, R81, R82, R93, R94, R120, R121, R132, R133: 2.2k; 0603
R2, R3, R7, R8, R9, R10, R16, R20, R21, R70, R71, R72, R73, R76, R79, R80, R109, R110, R111, R112, R115, R118, R119, R148, R149, R150, R151, R154: 5.1k; 0603
R5, R15, R17, R18, R19, R25, R38, R39, R41, R45, R47, R50, R63, R64, R65, R69, R77, R78, R83, R86, R89, R102, R103, R104, R108, R116, R117, R122, R125, R128, R141, R142, R143, R147, R155, R156: 100k; 0603
R6, R12, R14, R46, R74, R75, R85, R113, R114, R124, R152, R153: 4.7k; 0603
R11, R13, R27, R28, R32, R34, R42, R43, R44, R52, R53, R57, R59, R66, R67, R68, R84, R91, R92, R96, R98, R105, R106, R107, R123, R130, R131, R135, R137, R144, R145, R146: 1k; 0603
R23, R48, R87, R126: 10k; 0603
R24, R49, R88, R127: 10; 0603
R26, R51, R90, R129: 200k; 0603
R31, R36, R37, R56, R61, R62, R95, R100, R101, R134, R139, R140: 0; 0603
R33, R58, R97, R136: 100; 0603
R35, R60, R99, R138: 470; 0603
RI, RI1, RI2, RI3: JUMPER-SMT_2_NC_TRACE_SILK; SMT-JUMPER_2_NC_TRACE_SILK
RTS, RTS1, RTS4, RTS6: JUMPER-SMT_2_NC_TRACE_SILK; SMT-JUMPER_2_NC_TRACE_SILK
RTS2, RTS3, RTS5, RTS7: JUMPER-SMT_2_NO_SILK; SMT-JUMPER_2_NO_SILK
RX, RX1, RX4, RX6: JUMPER-SMT_2_NC_TRACE_SILK; SMT-JUMPER_2_NC_TRACE_SILK
RX2, RX3, RX5, RX7: JUMPER-SMT_2_NO_SILK; SMT-JUMPER_2_NO_SILK
RX_LED, RX_LED1, RX_LED2, RX_LED3: SMT-JUMPER_2_NC_TRACE_SILK
S1, S2, S5, S7: RESET; TACTILE_SWITCH_SMD_5.2MM
S3, S4, S6, S8: SARA_PWR; TACTILE_SWITCH_SMD_5.2MM
SERIAL, SERIAL1, SERIAL2, SERIAL3: 1X10_NO_SILK
TP1, TP2, TP3, TP4, TP5, TP6, TP7, TP8, TP9, TP10, TP11, TP12, TP13, TP14, TP15, TP16, TP17, TP18, TP19, TP20, TP21, TP22, TP23, TP24, TP25, TP26, TP27, TP28, TP29, TP30, TP31, TP32, TP33, TP34, TP35, TP36, TP37, TP38, TP39, TP40, TP41, TP42, TP43, TP44: TEST-POINT3; PAD.03X.03
TX, TX1, TX4, TX6: JUMPER-SMT_2_NC_TRACE_SILK; SMT-JUMPER_2_NC_TRACE_SILK
TX2, TX3, TX5, TX7: JUMPER-SMT_2_NO_SILK; SMT-JUMPER_2_NO_SILK
TX_LED, TX_LED1, TX_LED2, TX_LED3: SMT-JUMPER_2_NC_TRACE_SILK
U1, U9, U16, U23: SARA-R510M8S; SARA-LGA
U2, U13, U20, U27: CH340C; SO016
U3, U10, U17, U24: 3.3V; SOT23-5
U4, U14, U21, U28: CH340E_MSOP10; MSOP10
U5, U6, U15, U22: AP7361C-33FGE; UDFN-8
U7, U11, U18, U25: PCA9306; VSSOP_8PIN
U8, U12, U19, U26: 74HC1G04; SOT353
U$1, U$2, U$3, U$11, U$93, U$94, U$134, U$135, U$195, U$196, U$228, U$229, U$289, U$290, U$322, U$323: #3V3#1
U$4, U$167, U$261, U$355: #TX_LED#0
U$5, U$23, U$120, U$121, U$216, U$217, U$310, U$311: #SARA_I�C#0
U$6, U$7, U$136, U$137, U$230, U$231, U$324, U$325: #V_EXT#0
U$8, U$9, U$138, U$139, U$232, U$233, U$326, U$327: #3V3EN#0
U$10, U$13, U$140, U$141, U$234, U$235, U$328, U$329: ##RESET##0
U$12, U$22, U$95, U$96, U$197, U$198, U$291, U$292: #GND#0
U$14, U$142, U$236, U$330: #INT#0
U$15, U$71, U$182, U$183, U$276, U$277, U$370, U$371: #SARA_INT#0
U$16, U$17, U$143, U$144, U$237, U$238, U$331, U$332: #SARA_ON#0
U$18, U$145, U$239, U$333: RX0
U$19, U$87, U$92, U$115, U$194, U$213, U$288, U$307: #MEAS#2
U$20, U$168, U$262, U$356: #RX_LED#0
U$21, U$146, U$240, U$334: TX0
U$24, U$147, U$241, U$335: #TX#0
U$25, U$148, U$242, U$336: #RX#0
U$26, U$27, U$97, U$98, U$199, U$200, U$293, U$294: #SCL#3
U$28, U$149, U$243, U$337: #RTS#0
U$29, U$150, U$244, U$338: #DTR#0
U$30, U$37, U$102, U$103, U$201, U$202, U$295, U$296: #SDA#2
U$31, U$151, U$245, U$339: #DCD#0
U$32, U$152, U$246, U$340: #RI#0
U$33, U$153, U$247, U$341: #DSR#0
U$34, U$154, U$248, U$342: #CTS#0
U$35, U$155, U$249, U$343: #RXD_O#0
U$36, U$84, U$191, U$285: 3V37
U$38, U$156, U$250, U$344: #TXD_I#0
U$39, U$157, U$251, U$345: #CTS_O#0
U$40, U$158, U$252, U$346: #RTS_I#0
U$41, U$159, U$253, U$347: #DTR_TXD2_I#0
U$42, U$188, U$282, U$376: L10
U$43, U$160, U$254, U$348: #DCD_RXD2_O#0
U$44, U$161, U$255, U$349: #RXD2_O#0
U$45, U$85, U$192, U$286: RESET6
U$46, U$86, U$193, U$287: VIN8
U$47, U$162, U$256, U$350: #RI_CTS2_O#0
U$48, U$163, U$257, U$351: #CTS2_O#0
U$49, U$171, U$265, U$359: #DSR_O__RTS2_I#0
U$50, U$164, U$258, U$352: #RTS2_I#0
U$51, U$172, U$266, U$360: #V_EXT_DIODE#0
U$52, U$165, U$259, U$353: #OUT#0
U$53, U$166, U$260, U$354: #IN#0
U$54, U$169, U$263, U$357: #VIN_LED#0
U$55, U$56, U$77, U$78, U$81, U$82, U$104, U$105, U$189, U$190, U$203, U$204, U$283, U$284, U$297, U$298: #GND#4
U$57, U$58, U$106, U$107, U$205, U$206, U$299, U$300: #TP#0
U$59, U$60, U$108, U$109, U$207, U$208, U$301, U$302: #NI#0
U$61, U$170, U$264, U$358: #3V3_LED#0
U$62, U$63, U$173, U$174, U$267, U$268, U$361, U$362: #UART_2#0
U$64, U$65, U$175, U$176, U$269, U$270, U$363, U$364: #UART_1#0
U$66, U$67, U$177, U$178, U$271, U$272, U$365, U$366: #SARA_DIAG#0
U$68, U$80, U$83, U$112, U$114, U$179, U$211, U$212, U$273, U$305, U$306, U$367: #VCCIO#0
U$69, U$180, U$274, U$368: #GPIO2#0
U$70, U$181, U$275, U$369: #ANT_GNSS_PWR#0
U$72, U$187, U$281, U$375: #TXD2_I#0
U$73, U$184, U$278, U$372: LTE_CATEGORY_M10
U$74, U$185, U$279, U$373: LTE_CATEGORY_NB20
U$75, U$186, U$280, U$374: LTE_GNSS_BREAKOUT_#_SARA#R510M8S0
U$76, U$79, U$110, U$111, U$209, U$210, U$303, U$304: #3#3V#0
U$88, U$89, U$122, U$123, U$218, U$219, U$312, U$313: LTE0
U$90, U$116, U$214, U$308: NI0
U$91, U$117, U$215, U$309: TP0
U$99, U$100, U$124, U$125, U$220, U$221, U$314, U$315: GNSS0
U$101, U$127, U$223, U$317: ON0
U$113, U$126, U$222, U$316: SARA_ON0
U$118, U$132, U$226, U$320: #EXT_INT#0
U$119, U$133, U$227, U$321: #GPIO3#0
U$128, U$130, U$224, U$318: NANO0
U$129, U$131, U$225, U$319: SIM0
VIN_LED, VIN_LED1, VIN_LED2, VIN_LED3: SMT-JUMPER_2_NC_TRACE_SILK

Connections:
3.3V: 3V3_LED.2, C6.1, C14.1, C15.1, C16.1, C24.1, C25.1, D12.A, D13.A, D14.A, IC1.15, IC2.15, J5.6, J14.2, JP1.2, MEAS.2, MEAS.4, R15.2, R25.1, R26.2, R30.2, R38.2, R39.2, R45.1, RX_LED.2, SERIAL.1, TX_LED.2, U1.51, U1.52, U1.53, U2.4, U2.16, U4.7, U4.10, U8.5
3.3V1: 3V3_LED1.2, C37.1, C38.1, C39.1, C47.1, C48.1, C49.1, D20.A, D21.A, D22.A, IC3.15, IC4.15, J6.2, J12.6, JP3.2, MEAS1.2, MEAS1.4, R47.2, R50.1, R51.2, R55.2, R63.2, R64.2, R69.1, RX_LED1.2, SERIAL1.1, TX_LED1.2, U9.51, U9.52, U9.53, U12.5, U13.4, U13.16, U14.7, U14.10
3.3V2: 3V3_LED2.2, C62.1, C63.1, C64.1, C72.1, C73.1, C74.1, D34.A, D35.A, D36.A, IC5.15, IC6.15, J16.2, J24.6, JP6.2, MEAS2.2, MEAS2.4, R86.2, R89.1, R90.2, R94.2, R102.2, R103.2, R108.1, RX_LED2.2, SERIAL2.1, TX_LED2.2, U16.51, U16.52, U16.53, U19.5, U20.4, U20.16, U21.7, U21.10
3.3V3: 3V3_LED3.2, C87.1, C88.1, C89.1, C97.1, C98.1, C99.1, D48.A, D49.A, D50.A, IC7.15, IC8.15, J26.2, J32.6, JP9.2, MEAS3.2, MEAS3.4, R125.2, R128.1, R129.2, R133.2, R141.2, R142.2, R147.1, RX_LED3.2, SERIAL3.1, TX_LED3.2, U23.51, U23.52, U23.53, U26.5, U27.4, U27.16, U28.7, U28.10
3.3V_EN: J5.4, R5.1, U5.5
3.3V_EN1: J12.4, R41.1, U6.5
3.3V_EN2: J24.4, R83.1, U15.5
3.3V_EN3: J32.4, R122.1, U22.5
!RESET!: C9.1, J5.3, R15.1, S1.3, S1.4, U8.2
!RESET!1: C31.1, J12.3, R47.1, S2.3, S2.4, U12.2
!RESET!2: C56.1, J24.3, R86.1, S5.3, S5.4, U19.2
!RESET!3: C81.1, J32.3, R125.1, S7.3, S7.4, U26.2
ANT_REG_EN: Q9.3, R45.2, U3.3
ANT_REG_EN1: Q16.3, R69.2, U10.3
ANT_REG_EN2: Q24.3, R108.2, U17.3
ANT_REG_EN3: Q32.3, R147.2, U24.3
CTS: CTS.2, IC1.12, SERIAL.9
CTS1: CTS1.2, IC3.12, SERIAL1.9
CTS2: CTS4.2, IC5.12, SERIAL2.9
CTS3: CTS6.2, IC7.12, SERIAL3.9
DCD: DCD.2, IC2.13, RX2.2, SERIAL.6
DCD1: DCD1.2, IC4.13, RX3.2, SERIAL1.6
DCD2: DCD2.2, IC6.13, RX5.2, SERIAL2.6
DCD3: DCD3.2, IC8.13, RX7.2, SERIAL3.6
DSR: DSR.2, IC2.11, RTS2.2, SERIAL.8
DSR1: DSR1.2, IC4.11, RTS3.2, SERIAL1.8
DSR2: DSR2.2, IC6.11, RTS5.2, SERIAL2.8
DSR3: DSR3.2, IC8.11, RTS7.2, SERIAL3.8
DTR: DTR.2, IC2.14, R17.2, SERIAL.5, TX2.2
DTR1: DTR1.2, IC4.14, R77.2, SERIAL1.5, TX3.2
DTR2: DTR2.2, IC6.14, R116.2, SERIAL2.5, TX5.2
DTR3: DTR3.2, IC8.14, R155.2, SERIAL3.5, TX7.2
GND: C1.2, C3.2, C4.2, C5.2, C6.2, C7.2, C8.2, C9.2, C10.1, C11.1, C12.1, C13.2, C14.2, C15.2, C16.2, C17.2, C19.2, C20.2, C21.2, C22.2, C23.2, C24.2, C25.2, C26.2, D2.C, D4.C, D8.2, D8.5, D10.2, D11.2, DSR_DIR.1, E3.GND@0, E3.GND@1, E4.GND@0, E4.GND@1, IC1.2, IC1.8, IC1.9, IC1.10, IC2.1, IC2.9, IC2.10, J1.GND, J1.GND2, J2.GND, J2.GND2, J3.GND, J3.GND2, J5.8, J14.1, J17.C5, L1.P$2, Q1.2, Q2.2, Q3.2, Q4.2, Q7.2, Q8.2, Q9.2, R2.1, R3.1, R7.1, R8.1, R9.1, R10.1, R16.1, R17.1, R18.2, R19.1, S1.1, S1.2, S3.3, S3.4, SERIAL.10, U1.1, U1.3, U1.5, U1.14, U1.20, U1.21, U1.22, U1.30, U1.32, U1.43, U1.50, U1.54, U1.55, U1.57, U1.58, U1.59, U1.60, U1.61, U1.63, U1.64, U1.65, U1.66, U1.67, U1.68, U1.69, U1.70, U1.71, U1.72, U1.73, U1.74, U1.75, U1.76, U1.77, U1.78, U1.79, U1.80, U1.81, U1.82, U1.83, U1.84, U1.85, U1.86, U1.87, U1.88, U1.89, U1.90, U1.91, U1.92, U1.93, U1.94, U1.95, U1.96, U2.1, U3.2, U4.3, U5.4, U5.EP, U7.P1, U8.3
GND1: C2.2, C27.2, C28.2, C29.2, C30.2, C31.2, C32.2, C33.2, C34.1, C35.1, C36.1, C37.2, C38.2, C39.2, C41.2, C42.2, C43.2, C44.2, C45.2, C46.2, C47.2, C48.2, C49.2, C50.2, D15.C, D16.C, D17.2, D17.5, D18.2, D19.2, DSR_DIR1.1, E1.GND@0, E1.GND@1, E2.GND@0, E2.GND@1, IC3.2, IC3.8, IC3.9, IC3.10, IC4.1, IC4.9, IC4.10, J4.GND, J4.GND2, J6.1, J7.C5, J10.GND, J10.GND2, J11.GND, J11.GND2, J12.8, L4.P$2, Q6.2, Q10.2, Q12.2, Q13.2, Q14.2, Q15.2, Q16.2, R20.1, R21.1, R65.2, R70.1, R71.1, R72.1, R73.1, R76.1, R77.1, R78.1, S2.1, S2.2, S4.3, S4.4, SERIAL1.10, U6.4, U6.EP, U9.1, U9.3, U9.5, U9.14, U9.20, U9.21, U9.22, U9.30, U9.32, U9.43, U9.50, U9.54, U9.55, U9.57, U9.58, U9.59, U9.60, U9.61, U9.63, U9.64, U9.65, U9.66, U9.67, U9.68, U9.69, U9.70, U9.71, U9.72, U9.73, U9.74, U9.75, U9.76, U9.77, U9.78, U9.79, U9.80, U9.81, U9.82, U9.83, U9.84, U9.85, U9.86, U9.87, U9.88, U9.89, U9.90, U9.91, U9.92, U9.93, U9.94, U9.95, U9.96, U10.2, U11.P1, U12.3, U13.1, U14.3
GND2: C51.2, C52.2, C53.2, C54.2, C55.2, C56.2, C57.2, C58.2, C59.1, C60.1, C61.1, C62.2, C63.2, C64.2, C66.2, C67.2, C68.2, C69.2, C70.2, C71.2, C72.2, C73.2, C74.2, C75.2, D29.C, D30.C, D31.2, D31.5, D32.2, D33.2, DSR_DIR2.1, E5.GND@0, E5.GND@1, E6.GND@0, E6.GND@1, IC5.2, IC5.8, IC5.9, IC5.10, IC6.1, IC6.9, IC6.10, J15.GND, J15.GND2, J16.1, J18.C5, J22.GND, J22.GND2, J23.GND, J23.GND2, J24.8, L6.P$2, Q17.2, Q18.2, Q20.2, Q21.2, Q22.2, Q23.2, Q24.2, R79.1, R80.1, R104.2, R109.1, R110.1, R111.1, R112.1, R115.1, R116.1, R117.1, S5.1, S5.2, S6.3, S6.4, SERIAL2.10, U15.4, U15.EP, U16.1, U16.3, U16.5, U16.14, U16.20, U16.21, U16.22, U16.30, U16.32, U16.43, U16.50, U16.54, U16.55, U16.57, U16.58, U16.59, U16.60, U16.61, U16.63, U16.64, U16.65, U16.66, U16.67, U16.68, U16.69, U16.70, U16.71, U16.72, U16.73, U16.74, U16.75, U16.76, U16.77, U16.78, U16.79, U16.80, U16.81, U16.82, U16.83, U16.84, U16.85, U16.86, U16.87, U16.88, U16.89, U16.90, U16.91, U16.92, U16.93, U16.94, U16.95, U16.96, U17.2, U18.P1, U19.3, U20.1, U21.3
GND3: C76.2, C77.2, C78.2, C79.2, C80.2, C81.2, C82.2, C83.2, C84.1, C85.1, C86.1, C87.2, C88.2, C89.2, C91.2, C92.2, C93.2, C94.2, C95.2, C96.2, C97.2, C98.2, C99.2, C100.2, D43.C, D44.C, D45.2, D45.5, D46.2, D47.2, DSR_DIR3.1, E7.GND@0, E7.GND@1, E8.GND@0, E8.GND@1, IC7.2, IC7.8, IC7.9, IC7.10, IC8.1, IC8.9, IC8.10, J25.GND, J25.GND2, J26.1, J27.C5, J30.GND, J30.GND2, J31.GND, J31.GND2, J32.8, L8.P$2, Q25.2, Q26.2, Q28.2, Q29.2, Q30.2, Q31.2, Q32.2, R118.1, R119.1, R143.2, R148.1, R149.1, R150.1, R151.1, R154.1, R155.1, R156.1, S7.1, S7.2, S8.3, S8.4, SERIAL3.10, U22.4, U22.EP, U23.1, U23.3, U23.5, U23.14, U23.20, U23.21, U23.22, U23.30, U23.32, U23.43, U23.50, U23.54, U23.55, U23.57, U23.58, U23.59, U23.60, U23.61, U23.63, U23.64, U23.65, U23.66, U23.67, U23.68, U23.69, U23.70, U23.71, U23.72, U23.73, U23.74, U23.75, U23.76, U23.77, U23.78, U23.79, U23.80, U23.81, U23.82, U23.83, U23.84, U23.85, U23.86, U23.87, U23.88, U23.89, U23.90, U23.91, U23.92, U23.93, U23.94, U23.95, U23.96, U24.2, U25.P1, U26.3, U27.1, U28.3
unnamed: R6.2, VIN_LED.1
unnamed: JP1.3, R4.2
unnamed: JP1.1, R1.2
unnamed: D3.A, F2.2
unnamed: J2.A5, R7.2
unnamed: 3V3_LED.1, R11.2
unnamed: D2.A, R11.1
unnamed: D4.A, R6.1
unnamed: J2.B5, R8.2
unnamed: J1.A5, R2.2
unnamed: J1.B5, R3.2
unnamed: D5.A, F1.2
unnamed: F1.1, J2.VBUS1, J2.VBUS2
unnamed: J3.A5, R9.2
unnamed: C18.2, E3.SIG, L2.P$2
unnamed: C19.1, D10.1, L2.P$1, R23.2
unnamed: J3.B5, R10.2
unnamed: F3.1, J3.VBUS1, J3.VBUS2
unnamed: F2.1, J1.VBUS1, J1.VBUS2
unnamed: TX.1, U2.2
unnamed: RX.1, U2.3
unnamed: R26.1, U7.P7, U7.P8
unnamed: DSR_DIR.2, IC2.8
unnamed: C17.1, C20.1, R24.1, U3.5
unnamed: C21.1, FB1.1, R24.2, TP22.P$1
unnamed: Q2.1, R27.2
unnamed: Q4.1, R28.2
unnamed: R28.1, U8.4
unnamed: RTS.1, U2.14
unnamed: DTR.1, U2.13
unnamed: R31.2, U1.4
unnamed: Q1.1, R32.2
unnamed: J13.1, Q1.3, R33.1, R38.1
unnamed: D12.C, R33.2
unnamed: Q3.1, R34.2
unnamed: J19.1, Q3.3, R35.1, R39.1
unnamed: D13.C, R35.2
unnamed: R36.2, U1.13
unnamed: R37.2, U1.12
unnamed: Q8.1, R13.2
unnamed: DCD.1, U2.12
unnamed: Q8.3, Q9.1, R25.2
unnamed: JP19.2, Q5.2, R29.1
unnamed: RI.1, U2.11
unnamed: DSR.1, U2.10
unnamed: CTS.1, U2.9
unnamed: Q7.1, R42.2
unnamed: TX2.1, U4.8
unnamed: D14.C, R43.2
unnamed: RX2.1, U4.9
unnamed: RTS2.1, U4.4
unnamed: CTS2.1, U4.5
unnamed: R12.2, TX_LED.1
unnamed: D7.A, R12.1
unnamed: R14.2, RX_LED.1
unnamed: D9.A, R14.1
unnamed: D1.A, DVEXT.1, F4.1
unnamed: JP2.2, R13.1
unnamed: J4.A5, R20.2
unnamed: J4.B5, R21.2
unnamed: JP3.3, R40.2
unnamed: JP3.1, R22.2
unnamed: 3V3_LED1.1, R44.2
unnamed: D15.A, R44.1
unnamed: R46.2, VIN_LED1.1
unnamed: D16.A, R46.1
unnamed: C40.2, E1.SIG, L3.P$2
unnamed: C41.1, D18.1, L3.P$1, R48.2
unnamed: C42.1, C43.1, R49.1, U10.5
unnamed: C44.1, FB2.1, R49.2, TP21.P$1
unnamed: R51.1, U11.P7, U11.P8
unnamed: Q6.1, R52.2
unnamed: Q10.1, R53.2
unnamed: R53.1, U12.4
unnamed: R56.2, U9.4
unnamed: Q12.1, R57.2
unnamed: J8.1, Q12.3, R58.1, R63.1
unnamed: D20.C, R58.2
unnamed: Q13.1, R59.2
unnamed: J9.1, Q13.3, R60.1, R64.1
unnamed: D21.C, R60.2
unnamed: R61.2, U9.13
unnamed: R62.2, U9.12
unnamed: Q14.1, R66.2
unnamed: D22.C, R67.2
unnamed: DSR_DIR1.2, IC4.8
unnamed: Q15.1, R68.2
unnamed: Q15.3, Q16.1, R50.2
unnamed: JP4.2, Q11.2, R54.1
unnamed: D23.A, F5.2
unnamed: J10.A5, R70.2
unnamed: J10.B5, R71.2
unnamed: D24.A, F6.2
unnamed: F6.1, J10.VBUS1, J10.VBUS2
unnamed: J11.A5, R72.2
unnamed: J11.B5, R73.2
unnamed: F5.1, J4.VBUS1, J4.VBUS2
unnamed: TX1.1, U13.2
unnamed: RX1.1, U13.3
unnamed: RTS1.1, U13.14
unnamed: DTR1.1, U13.13
unnamed: DCD1.1, U13.12
unnamed: RI1.1, U13.11
unnamed: DSR1.1, U13.10
unnamed: CTS1.1, U13.9
unnamed: TX3.1, U14.8
unnamed: RX3.1, U14.9
unnamed: RTS3.1, U14.4
unnamed: CTS3.1, U14.5
unnamed: F7.1, J11.VBUS1, J11.VBUS2
unnamed: R74.2, RX_LED1.1
unnamed: D26.A, R74.1
unnamed: R75.2, TX_LED1.1
unnamed: D27.A, R75.1
unnamed: D28.A, DVEXT1.1, F8.1
unnamed: JP5.2, R68.1
unnamed: J15.A5, R79.2
unnamed: J15.B5, R80.2
unnamed: JP6.3, R82.2
unnamed: JP6.1, R81.2
unnamed: 3V3_LED2.1, R84.2
unnamed: D29.A, R84.1
unnamed: R85.2, VIN_LED2.1
unnamed: D30.A, R85.1
unnamed: C65.2, E5.SIG, L5.P$2
unnamed: C66.1, D32.1, L5.P$1, R87.2
unnamed: C67.1, C68.1, R88.1, U17.5
unnamed: C69.1, FB3.1, R88.2, TP33.P$1
unnamed: R90.1, U18.P7, U18.P8
unnamed: Q17.1, R91.2
unnamed: Q18.1, R92.2
unnamed: R92.1, U19.4
unnamed: R95.2, U16.4
unnamed: Q20.1, R96.2
unnamed: J20.1, Q20.3, R97.1, R102.1
unnamed: D34.C, R97.2
unnamed: Q21.1, R98.2
unnamed: J21.1, Q21.3, R99.1, R103.1
unnamed: D35.C, R99.2
unnamed: R100.2, U16.13
unnamed: R101.2, U16.12
unnamed: Q22.1, R105.2
unnamed: D36.C, R106.2
unnamed: DSR_DIR2.2, IC6.8
unnamed: Q23.1, R107.2
unnamed: Q23.3, Q24.1, R89.2
unnamed: JP7.2, Q19.2, R93.1
unnamed: D37.A, F9.2
unnamed: J22.A5, R109.2
unnamed: J22.B5, R110.2
unnamed: D38.A, F10.2
unnamed: F10.1, J22.VBUS1, J22.VBUS2
unnamed: J23.A5, R111.2
unnamed: J23.B5, R112.2
unnamed: F9.1, J15.VBUS1, J15.VBUS2
unnamed: TX4.1, U20.2
unnamed: RX4.1, U20.3
unnamed: RTS4.1, U20.14
unnamed: DTR2.1, U20.13
unnamed: DCD2.1, U20.12
unnamed: RI2.1, U20.11
unnamed: DSR2.1, U20.10
unnamed: CTS4.1, U20.9
unnamed: TX5.1, U21.8
unnamed: RX5.1, U21.9
unnamed: RTS5.1, U21.4
unnamed: CTS5.1, U21.5
unnamed: F11.1, J23.VBUS1, J23.VBUS2
unnamed: R113.2, RX_LED2.1
unnamed: D40.A, R113.1
unnamed: R114.2, TX_LED2.1
unnamed: D41.A, R114.1
unnamed: D42.A, DVEXT2.1, F12.1
unnamed: JP8.2, R107.1
unnamed: J25.A5, R118.2
unnamed: J25.B5, R119.2
unnamed: JP9.3, R121.2
unnamed: JP9.1, R120.2
unnamed: 3V3_LED3.1, R123.2
unnamed: D43.A, R123.1
unnamed: R124.2, VIN_LED3.1
unnamed: D44.A, R124.1
unnamed: C90.2, E7.SIG, L7.P$2
unnamed: C91.1, D46.1, L7.P$1, R126.2
unnamed: C92.1, C93.1, R127.1, U24.5
unnamed: C94.1, FB4.1, R127.2, TP44.P$1
unnamed: R129.1, U25.P7, U25.P8
unnamed: Q25.1, R130.2
unnamed: Q26.1, R131.2
unnamed: R131.1, U26.4
unnamed: R134.2, U23.4
unnamed: Q28.1, R135.2
unnamed: J28.1, Q28.3, R136.1, R141.1
unnamed: D48.C, R136.2
unnamed: Q29.1, R137.2
unnamed: J29.1, Q29.3, R138.1, R142.1
unnamed: D49.C, R138.2
unnamed: R139.2, U23.13
unnamed: R140.2, U23.12
unnamed: Q30.1, R144.2
unnamed: D50.C, R145.2
unnamed: DSR_DIR3.2, IC8.8
unnamed: Q31.1, R146.2
unnamed: Q31.3, Q32.1, R128.2
unnamed: JP10.2, Q27.2, R132.1
unnamed: D51.A, F13.2
unnamed: J30.A5, R148.2
unnamed: J30.B5, R149.2
unnamed: D52.A, F14.2
unnamed: F14.1, J30.VBUS1, J30.VBUS2
unnamed: J31.A5, R150.2
unnamed: J31.B5, R151.2
unnamed: F13.1, J25.VBUS1, J25.VBUS2
unnamed: TX6.1, U27.2
unnamed: RX6.1, U27.3
unnamed: RTS6.1, U27.14
unnamed: DTR3.1, U27.13
unnamed: DCD3.1, U27.12
unnamed: RI3.1, U27.11
unnamed: DSR3.1, U27.10
unnamed: CTS6.1, U27.9
unnamed: TX7.1, U28.8
unnamed: RX7.1, U28.9
unnamed: RTS7.1, U28.4
unnamed: CTS7.1, U28.5
unnamed: F15.1, J31.VBUS1, J31.VBUS2
unnamed: R152.2, RX_LED3.1
unnamed: D54.A, R152.1
unnamed: R153.2, TX_LED3.1
unnamed: D55.A, R153.1
unnamed: D56.A, DVEXT3.1, F16.1
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

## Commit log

2021-03-04 Updates after concept review
    [SparkFun_SARA-R5_Breakout.brd, SparkFun_SARA-R5_Breakout.sch]
2021-03-09 Update SparkFun_SARA-R5_Breakout.brd
    Added L1 label to GNSS connector
    [SparkFun_SARA-R5_Breakout.brd]
2021-03-10 Proto changes
    Changed the version to v01
    Changed led color of D7 from yellow to green
    Switched text to vector
    [SparkFun_SARA-R5_Breakout.brd, SparkFun_SARA-R5_Breakout.sch]
2021-03-10 Updated file names
    [SparkFun_LTE_GNSS_Breakout_SARA-R510M8S.brd, SparkFun_LTE_GNSS_Breakout_SARA-R510M8S.sch]
2021-05-17 V10
    Added 100k Pulldown resistors to RTS and DTR
    Moved "L1" label from the top of the board to the bottom
    [SparkFun_LTE_GNSS_Breakout_SARA-R510M8S.brd, SparkFun_LTE_GNSS_Breakout_SARA-R510M8S.sch]
2021-05-18 V10 design review changes
    -Updated Schematic PDF
    -Added new parts to sparkfun libraries
    -Fixed labels for schematic sections
    [SparkFun_LTE_GNSS_Breakout_SARA-R510M8S.brd, SparkFun_LTE_GNSS_Breakout_SARA-R510M8S.sch]
2021-05-19 Added V10 Panel
    [SparkFun_LTE_GNSS_Breakout_SARA-R510M8S-Panel.GBL, SparkFun_LTE_GNSS_Breakout_SARA-R510M8S-Panel.GBO, SparkFun_LTE_GNSS_Breakout_SARA-R510M8S-Panel.GBP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]

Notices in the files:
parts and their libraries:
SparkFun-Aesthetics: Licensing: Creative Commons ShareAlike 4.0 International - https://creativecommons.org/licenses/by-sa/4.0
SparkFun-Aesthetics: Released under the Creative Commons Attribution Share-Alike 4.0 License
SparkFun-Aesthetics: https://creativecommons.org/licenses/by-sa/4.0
